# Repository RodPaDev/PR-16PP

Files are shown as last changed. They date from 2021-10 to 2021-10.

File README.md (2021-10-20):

# Kicad Mechanical Keyboard Template

This is a template project _(without actually being a KiCad template)_, it aims to facilitate the repetitiveness of starting a new mechanical keyboard project from scratch.

It already has the following libraries added

 - [MX_Alps_Hybrid by ai03](https://github.com/ai03-2725/MX_Alps_Hybrid)
 - [random-keyboard-parts by ai03](https://github.com/ai03-2725/random-keyboard-parts.pretty)

----

## Get Started

You need to install [Git](https://git-scm.com/) for the next step.

1. Clone this project and the submodules

```
git clone git@github.com:RodPaDev/kicad-keyboard-template.git <PROJECT_NAME>
or
git clone https://github.com/RodPaDev/kicad-keyboard-template.git <PROJECT_NAME>

git submodules init
git submodules update
```

2. Rename files:

If you don't have python installed, just do it manually.

**Automatic:**
```
python rename.py <YOUR_PROJECT_NAME>

If you make a typo you'll have to change the preifx variable to the current name (the one you entered)
```

**Manual:**

Rename the following files:
```
Keyboard_Template.kicad_pcb
Keyboard_Template.pro
Keyboard_Template.sch

```

## Notes:

This does not have anything done yet, the implementation is up to you. However, I may add branches in the future with some of the more "generic" parts already implemented and ready to use.

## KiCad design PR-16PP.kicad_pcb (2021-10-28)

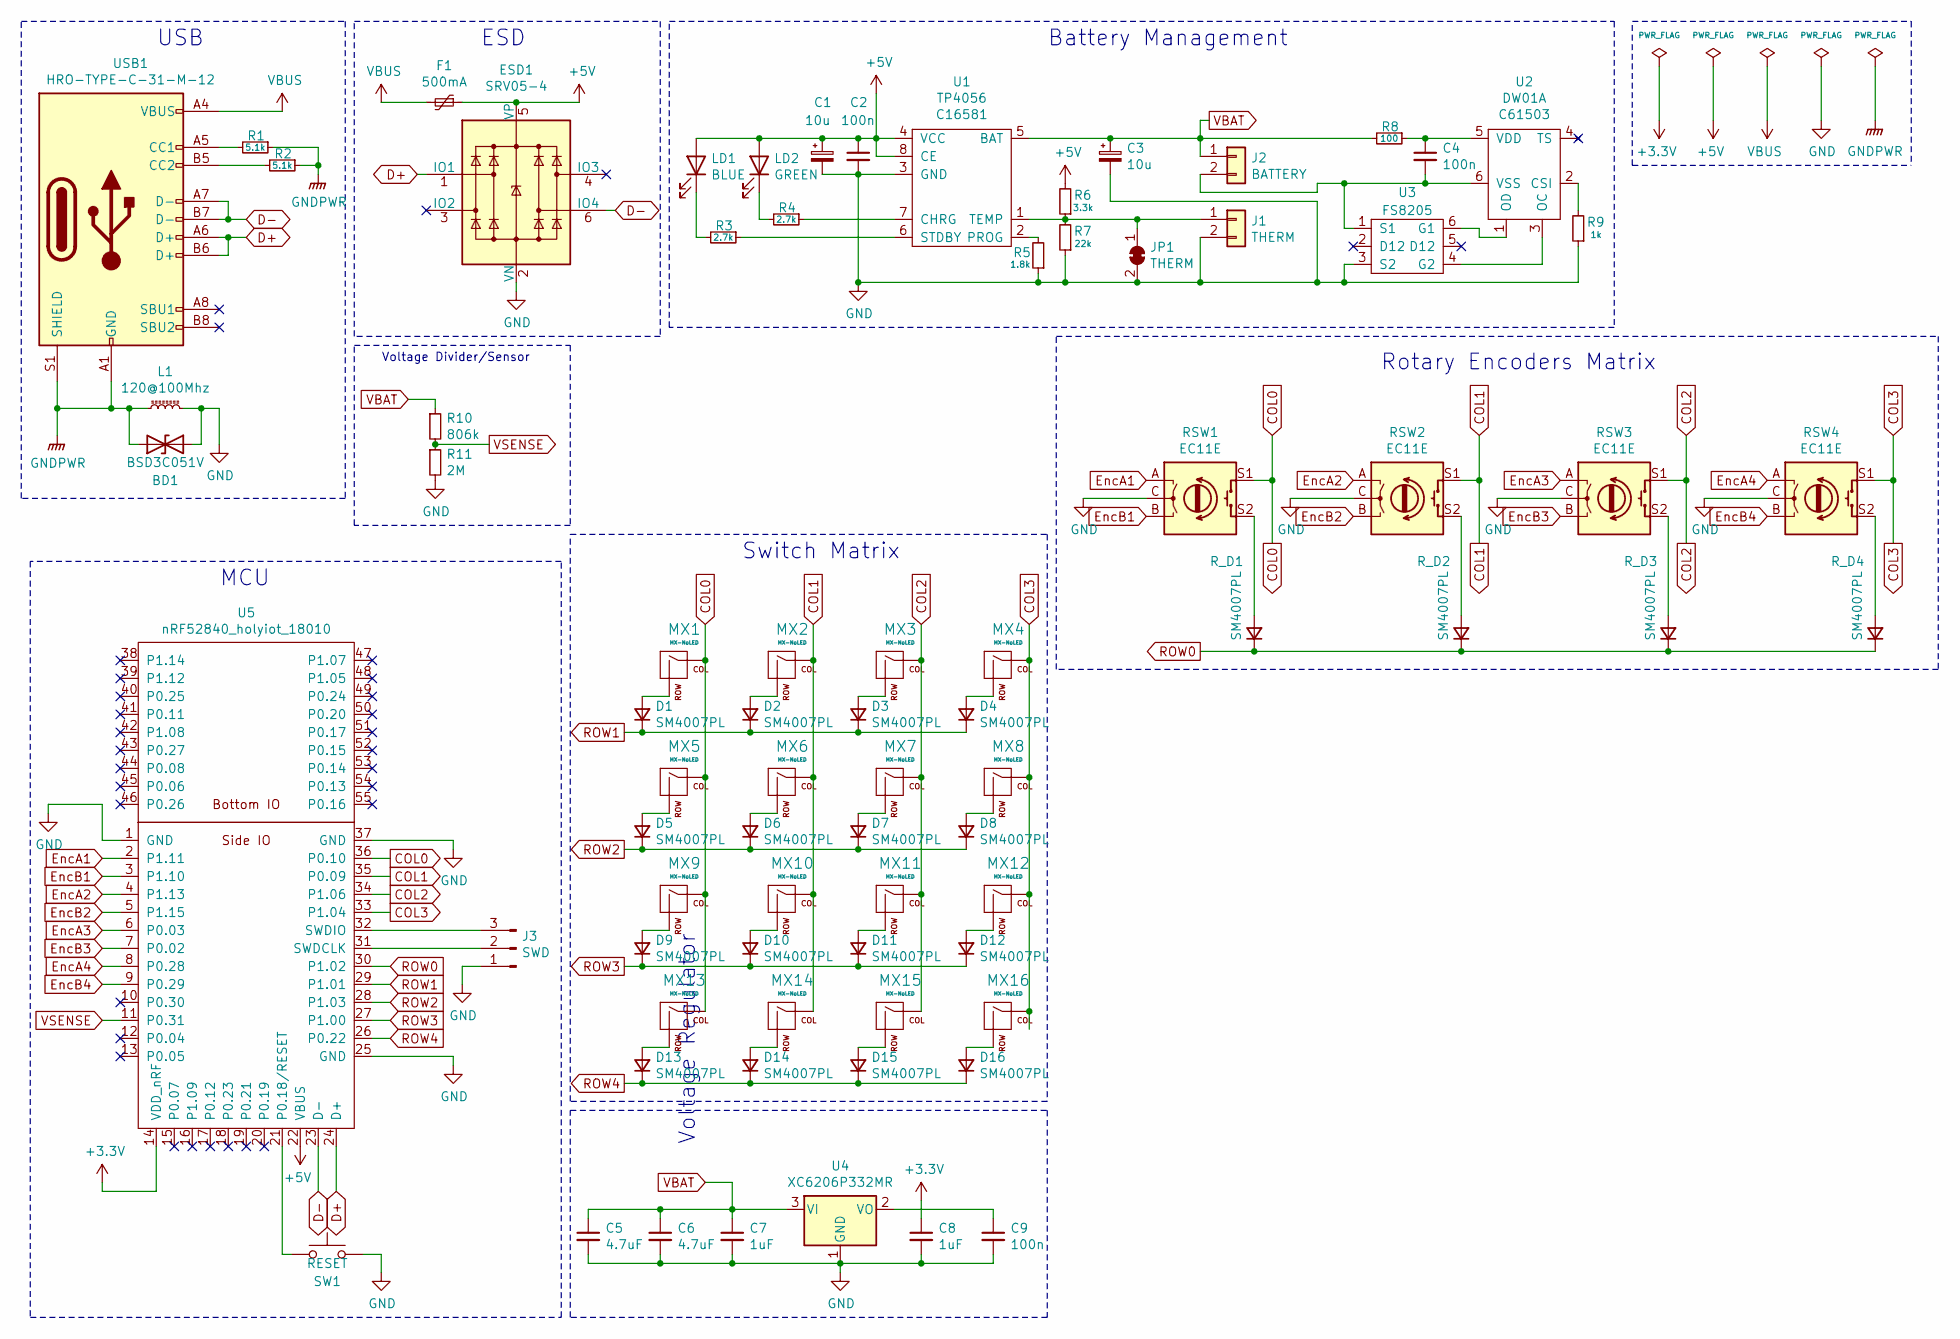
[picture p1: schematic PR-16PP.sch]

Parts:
BD1: BSD3C051V; SOT-23_stealth
C1, C3: 10u; C_0603_1608Metric
C2, C4, C9: 100n; C_0603_1608Metric
C5, C6: 4.7uF; C_0603_1608Metric
C7, C8: 1uF; C_0603_1608Metric
D1, D2, D3, D4, D5, D6, D7, D8, D9, D10, D11, D12, D13, D14, D15, D16: SM4007PL; D_SOD-123-Pretty
ESD1: SRV05-4; SOT-23-6
F1: 500mA; Fuse_0603_1608Metric
J1: THERM; JST_SH_SM02B-SRSS-TB_1x02-1MP_P1.00mm_Horizontal
J2: BATTERY; JST_SH_SM02B-SRSS-TB_1x02-1MP_P1.00mm_Horizontal
J3: SWD; PinHeader_1x03_P2.54mm_Vertical
JP1: THERM; SolderJumper-2_P1.3mm_Bridged_RoundedPad1.0x1.5mm
L1: 120@100Mhz; L_0603_1608Metric
LD1: BLUE; LED_0603_1608Metric
LD2: GREEN; LED_0603_1608Metric
MX1, MX2, MX3, MX4, MX5, MX6, MX7, MX8, MX9, MX10, MX11, MX12, MX13, MX14, MX15, MX16: MX-NoLED; MXOnly-1U-Hotswap-Antishear
R1, R2: 5.1k; R_0603_1608Metric
R3, R4: 2.7k; R_0603_1608Metric
R5: 1.8k; R_0603_1608Metric
R6: 3.3k; R_0603_1608Metric
R7: 22k; R_0603_1608Metric
R8: 100; R_0603_1608Metric
R9: 1k; R_0603_1608Metric
R10: 806k; R_0603_1608Metric
R11: 2M; R_0603_1608Metric
RSW1, RSW2, RSW3, RSW4: EC11E; RotaryEncoder_Alps_EC11E-Switch_Vertical_H20mm
R_D1, R_D2, R_D3, R_D4: SM4007PL; D_SOD-123-Pretty
SW1: RESET; SKQG-1155865
U1: TP4056; SOP-8-1EP_4.57x4.57mm_P1.27mm_EP4.57x4.45mm; LCSC C16581
U2: DW01A; SOT-23-6; LCSC C61503
U3: FS8205; SOT-23-6; LCSC C32254
U4: XC6206P332MR; SOT-23; LCSC C5446
U5: nRF52840_holyiot_18010
USB1: HRO-TYPE-C-31-M-12; USB_C_Receptacle_HRO_TYPE-C-31-M-12

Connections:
+3V3: C8.1, U5.14 (VDD_nRF)
+5V: C1.1, C2.1, ESD1.5 (VP), F1.1, LD1.2 (A), LD2.2 (A), R6.2, U1.4 (VCC), U1.8 (CE), U5.22 (VBUS)
COL0: MX1.1 (COL), MX5.1 (COL), MX9.1 (COL), MX13.1 (COL), RSW1.S1, U5.36 (P0.10)
COL1: MX2.1 (COL), MX6.1 (COL), MX10.1 (COL), MX14.1 (COL), RSW2.S1, U5.35 (P0.09)
COL2: MX3.1 (COL), MX7.1 (COL), MX11.1 (COL), MX15.1 (COL), RSW3.S1, U5.34 (P1.06)
COL3: MX4.1 (COL), MX8.1 (COL), MX12.1 (COL), MX16.1 (COL), RSW4.S1, U5.33 (P1.04)
D+: ESD1.1 (IO1), U5.24 (D+), USB1.A6 (D+), USB1.B6 (D+)
D-: ESD1.6 (IO4), U5.23 (D-), USB1.A7 (D-), USB1.B7 (D-)
EncA1: RSW1.A, U5.2 (P1.11)
EncA2: RSW2.A, U5.4 (P1.13)
EncA3: RSW3.A, U5.6 (P0.03)
EncA4: RSW4.A, U5.8 (P0.28)
EncB1: RSW1.B, U5.3 (P1.10)
EncB2: RSW2.B, U5.5 (P1.15)
EncB3: RSW3.B, U5.7 (P0.02)
EncB4: RSW4.B, U5.9 (P0.29)
GND: BD1.2 (A2), C1.2, C2.2, C3.2, C5.2, C6.2, C7.2, C8.2, C9.2, ESD1.2 (VN), J1.2, J3.1, JP1.2 (B), L1.2, R5.1, R7.1, R9.1, R11.2, RSW1.C, RSW2.C, RSW3.C, RSW4.C, SW1.2, U1.3 (GND), U3.3 (S2), U4.1 (GND), U5.1 (GND), U5.25 (GND), U5.37 (GND)
GNDPWR: BD1.1 (A1), L1.1, R1.1, R2.1, USB1.A1 (GND), USB1.A12 (GND), USB1.B1 (GND), USB1.B12 (GND), USB1.S1 (SHIELD)
unnamed: C4.1, R8.1, U2.5 (VDD)
unnamed: C4.2, J2.2, U2.6 (VSS), U3.1 (S1)
unnamed: C9.1, U4.2 (VO)
unnamed: D1.2 (A), MX1.2 (ROW)
unnamed: D2.2 (A), MX2.2 (ROW)
unnamed: D3.2 (A), MX3.2 (ROW)
unnamed: D4.2 (A), MX4.2 (ROW)
unnamed: D5.2 (A), MX5.2 (ROW)
unnamed: D6.2 (A), MX6.2 (ROW)
unnamed: D7.2 (A), MX7.2 (ROW)
unnamed: D8.2 (A), MX8.2 (ROW)
unnamed: D9.2 (A), MX9.2 (ROW)
unnamed: D10.2 (A), MX10.2 (ROW)
unnamed: D11.2 (A), MX11.2 (ROW)
unnamed: D12.2 (A), MX12.2 (ROW)
unnamed: D13.2 (A), MX13.2 (ROW)
unnamed: D14.2 (A), MX14.2 (ROW)
unnamed: D15.2 (A), MX15.2 (ROW)
unnamed: D16.2 (A), MX16.2 (ROW)
unnamed: J1.1, JP1.1 (A), R6.1, R7.2, U1.1 (TEMP)
unnamed: J3.2, U5.31 (SWDCLK)
unnamed: J3.3, U5.32 (SWDIO)
unnamed: LD1.1 (K), R3.2
unnamed: LD2.1 (K), R4.2
unnamed: R1.2, USB1.A5 (CC1)
unnamed: R2.2, USB1.B5 (CC2)
unnamed: R3.1, U1.6 (STDBY)
unnamed: R4.1, U1.7 (CHRG)
unnamed: R5.2, U1.2 (PROG)
unnamed: R9.2, U2.2 (CSI)
unnamed: RSW1.S2, R_D1.2 (A)
unnamed: RSW2.S2, R_D2.2 (A)
unnamed: RSW3.S2, R_D3.2 (A)
unnamed: RSW4.S2, R_D4.2 (A)
unnamed: SW1.1, U5.21 (P0.18/RESET)
unnamed: U2.1 (OD), U3.6 (G1)
unnamed: U2.3 (OC), U3.4 (G2)
ROW0: R_D1.1 (K), R_D2.1 (K), R_D3.1 (K), R_D4.1 (K), U5.30 (P1.02)
ROW1: D1.1 (K), D2.1 (K), D3.1 (K), D4.1 (K), U5.29 (P1.01)
ROW2: D5.1 (K), D6.1 (K), D7.1 (K), D8.1 (K), U5.28 (P1.03)
ROW3: D9.1 (K), D10.1 (K), D11.1 (K), D12.1 (K), U5.27 (P1.00)
ROW4: D13.1 (K), D14.1 (K), D15.1 (K), D16.1 (K), U5.26 (P0.22)
VBAT: C3.1, C5.1, C6.1, C7.1, J2.1, R8.2, R10.1, U1.5 (BAT), U4.3 (VI)
VBUS: F1.2, USB1.A4 (VBUS), USB1.A9 (VBUS), USB1.B4 (VBUS), USB1.B9 (VBUS)
VSENSE: R10.2, R11.1, U5.11 (P0.31)

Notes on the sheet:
Battery Management
USB
Voltage Regulator
Switch Matrix
MCU
Voltage Divider/Sensor
Rotary Encoders Matrix
ESD

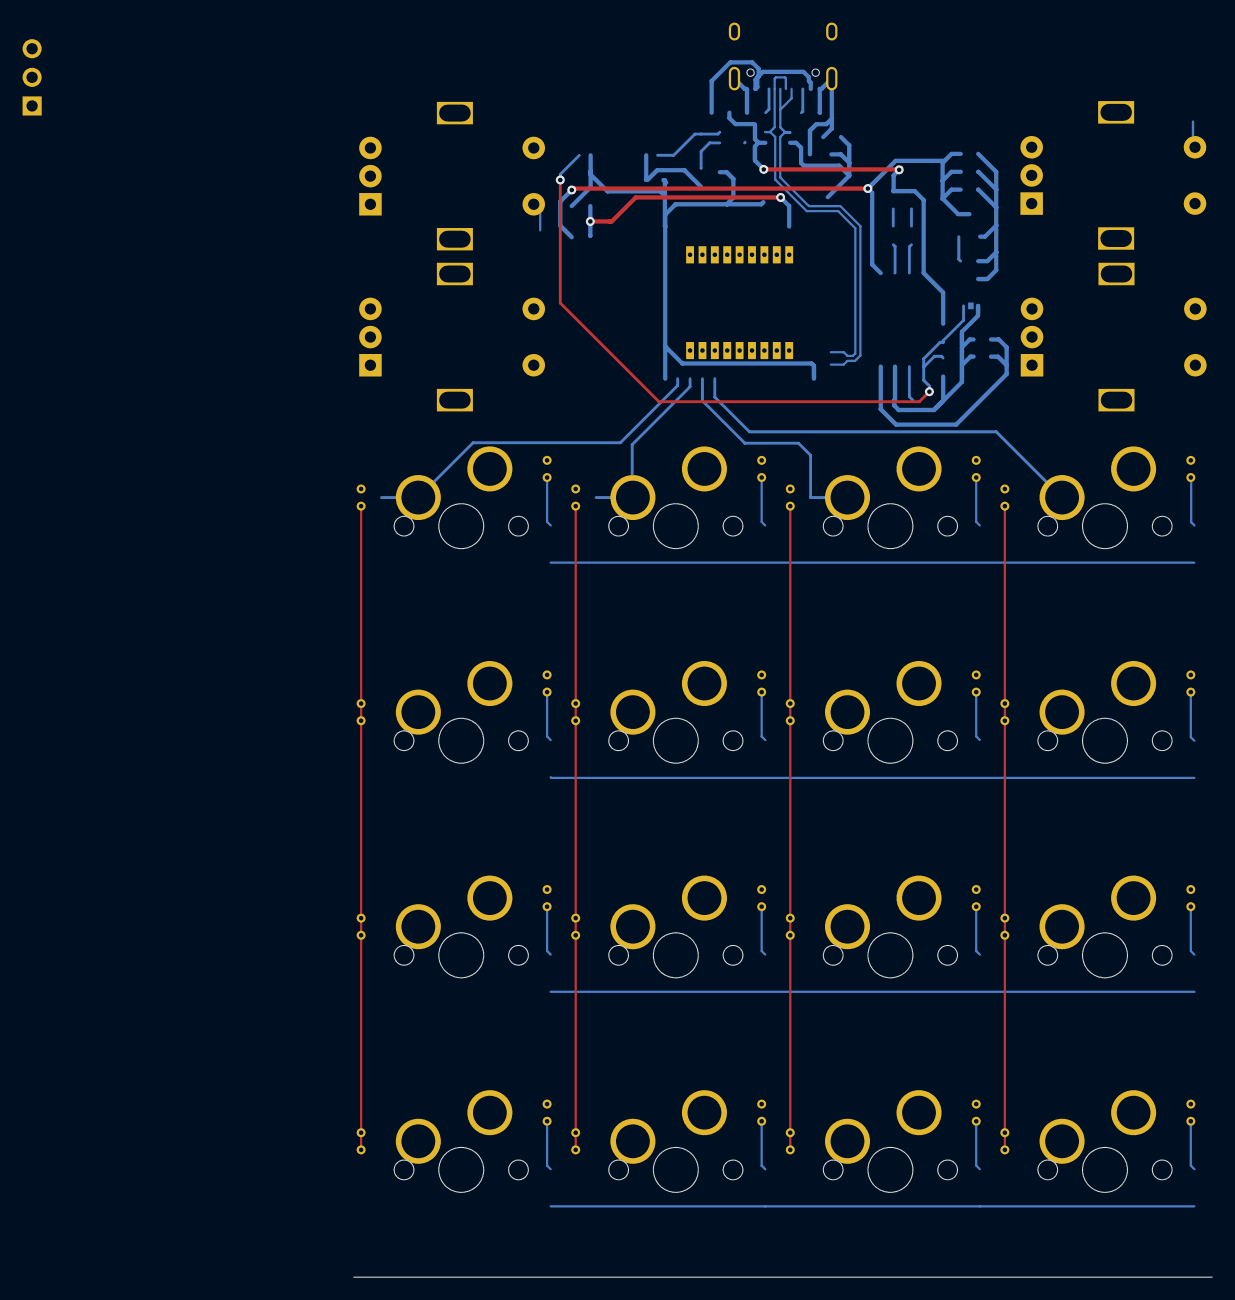
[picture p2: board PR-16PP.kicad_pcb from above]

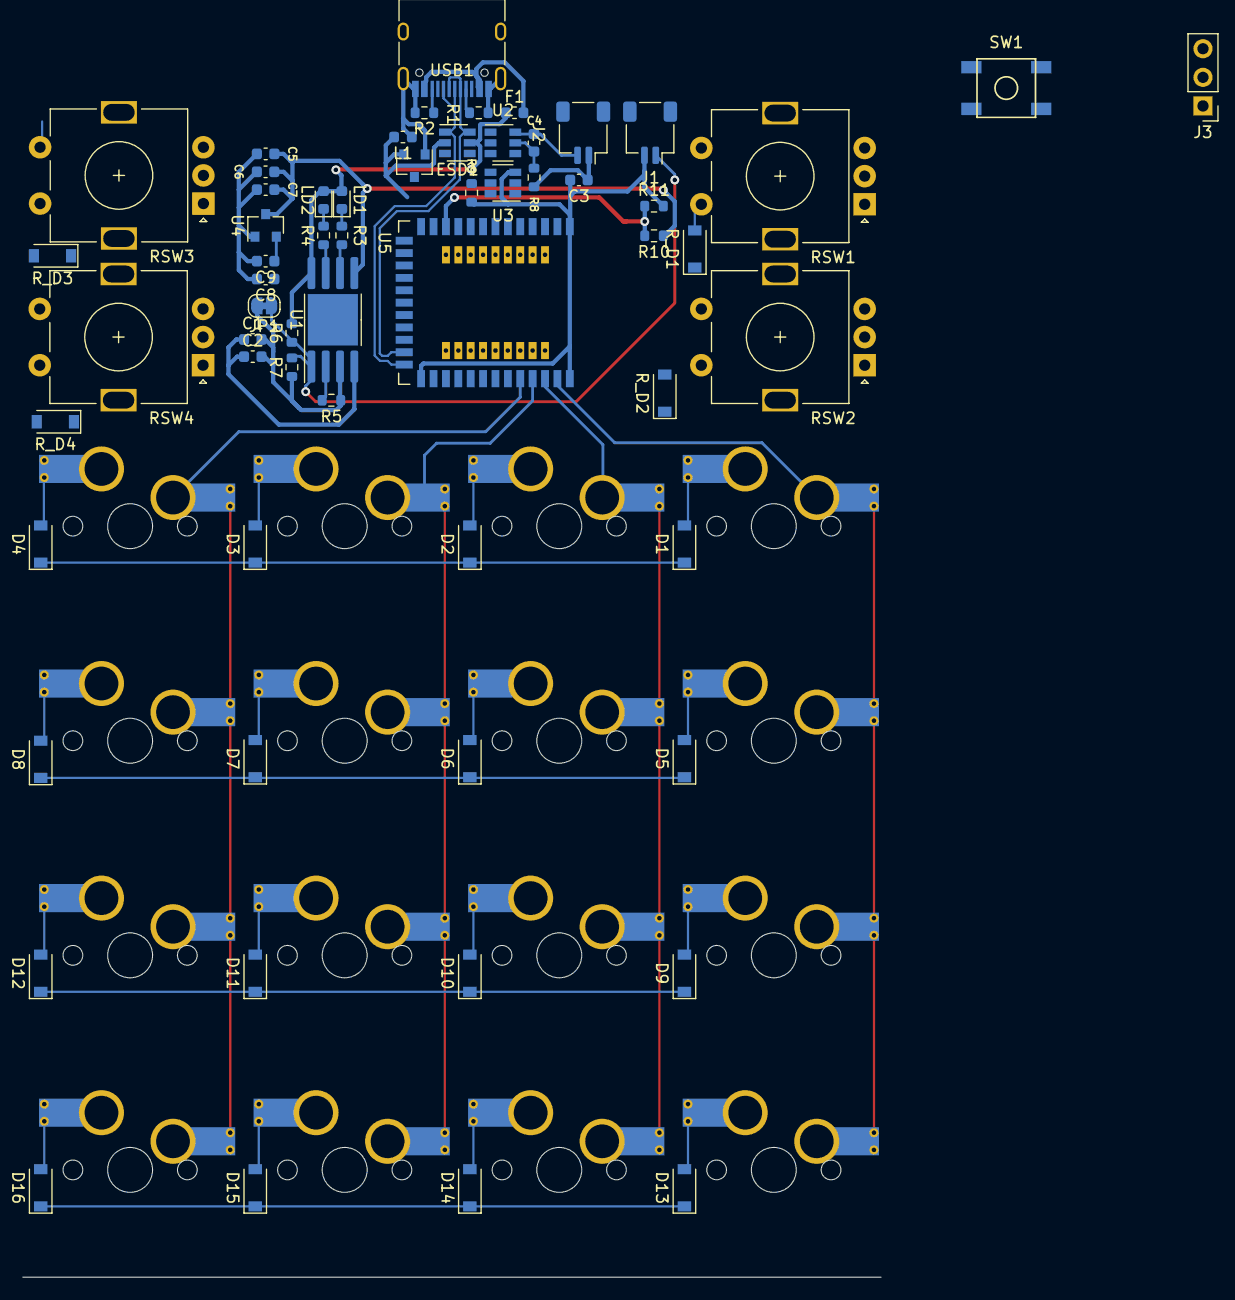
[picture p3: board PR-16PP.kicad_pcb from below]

Board: 2 copper layers, 77 parts (61 on the bottom side), 63 nets.

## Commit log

2021-10-20 intial commit
    [PR-16PP.kicad_pcb, PR-16PP.sch, USB.sch]
2021-10-20 finish basic schematic
    [PR-16PP.sch, USB.sch]
